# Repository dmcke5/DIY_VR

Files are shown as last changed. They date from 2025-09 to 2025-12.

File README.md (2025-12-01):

# CNCDan - DIY VR
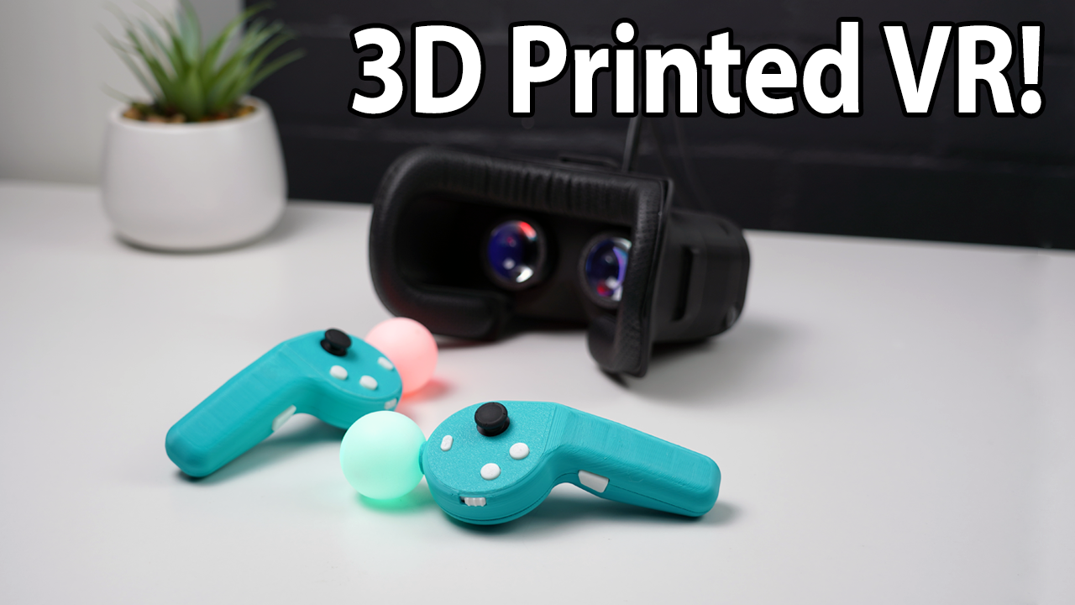
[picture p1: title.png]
DIY VR


A fully 3D printed headset design for VR!

[Project Video Link V1.0](https://youtu.be/pbNyW5GsUQc)

[Project Video Link V2.0](https://youtu.be/7cRuXjuuTN8)

#### Features

- 2880x1440p Resolution
- 120hz Refresh Rate
- Inidividually adjustable IPD
- Easily replaceable lenses
- Compatible with HTC Vive Pro Head Pads
- Adjustable brightness
- SteamVR compatible 3 DOF head tracking or 6DOF using PSMoveServiceEX
- Support for wireless controllers https://github.com/dmcke5/DIY_VR_Controllers

This git has been updated for my Version 2 DIY VR design. All of the original files are still here, they've just been renamed to V1.0 if they are no longer in use (along with the original Readme).

I have included a full model of both versions in .STEP format to aid with assembly!

#### Bill of Materials

1x Display Set - https://www.aliexpress.com/item/32975284107.html

1x GY91 IMU board - https://www.aliexpress.com/item/1005005180963415.html

2x NRF24L01 Wireless Module - https://www.aliexpress.com/item/1005007199963170.html

1x 40mm Ping Pong Balls - https://www.aliexpress.com/item/1005009969506572.html

1x Tactile switch - https://www.aliexpress.com/item/1005006497849129.html

2x 3mm x 145mm Stainless Rod - https://www.aliexpress.com/item/1005009347568195.html

6x 3x6(OD) 4mm(L) Brass Bushings - https://www.aliexpress.com/item/1005008668212038.html

1x Arduino Pro Micro USB-C Version - https://www.aliexpress.com/item/32846843498.html

1x Pair 34mm Diameter 45mm Focal Length Lenses - https://www.aliexpress.com/item/1005004324103470.html

1x 1M 25mm Nylon Strapping - https://www.aliexpress.com/item/1005008515249414.html

1x HTC Vive Pro Face Pad - https://www.aliexpress.com/item/1005001324834346.html

#### Hardware

16x M3x5x5 Threaded Inserts

4x M3x12 SHCS

10x M3x8 SHCS

4x M3x12 Standoffs

### Instructions

#### Printing

First, you'll need one of every part printed, except for these items that require multiples:

3x DIY VR Buckle 

2x DIY VR Lens Retainer

2x DIY VR Thumbscrew Head

The files with V1.0 names can be ignored, unless you are specifically making the old version in which case, you can print them and disregard any V2.0 files. Refer the to V1.0 readme for specific Instructions.

There are print recomendations for most of the important parts in the first video.
The V2.0 front cover is much easier to print than V1.0 and can be printed front down with minimal supports.

#### Electronics

Only three SMD parts are required to assemble the PCB, 1x MCP1792-3302xCB and two 470nF 0603 Capacitors. The two NRF modules can be soldered in as usual, but when you solder in the IMU module ensure you remove the black plastic spacer from the pins to ensure the module is sitting flat against the PCB. The Arduino needs to be installed WITH the black plastic spacers, otherwise its USB port won't align with the opening.

Once the head tracker board is assembled, there are three sets of pads you will need to connect. The two pads labelled "Calibrate" are to be wired to the tactile switch on the side of the headset. The three pads labelled VCC, GND and DO are to be connected to an addressable RGB LED that is used for the pingpong ball.
The final two pads labelled VCC and GND are to supply power to your display driver and should be connected accordingly.

#### Head Tracking Software/Firmware

Revision 2.0 of the head tracker relies on the HadesVR driver. I have included a slightly modified version of their firmware here, which you will need to use as it adds support for the addressable RGB led used for the tracking bulb.

Refer to the HadesVR github page for upload and config instructions: 
https://github.com/HadesVR/Basic-HMD-PCB?tab=readme-ov-file#uploading-the-firmware-and-calibrating-the-sensors

If you're using the 6DOF tracking, you will also need to go through the PSMoveServiceEX Setup process. Their documentation is here: https://github.com/Timocop/PSMoveServiceEx/wiki

#### Physical Build

Refer to both of the project videos for build steps and I will add anything here in future if anyone requests extra information!

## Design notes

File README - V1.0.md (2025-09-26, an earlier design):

# CNCDan - DIY VR
DIY VR

A fully 3D printed headset design for VR!

[Project Video Link](https://youtu.be/pbNyW5GsUQc)

#### Features

- 2880x1440p Resolution
- Inidividually adjustable IPD
- Easily replaceable lenses
- Compatible with HTC Vive Pro Head Pads
- Adjustable brightness
- Duplicate or extend display modes for VR or regular viewing
- SteamVR compatible 3 DOF head tracking

Please note! As I mentioned in the video, the displays I purchased can't actually do the 90hz they claim in the full 2880x1440 display mode which is needed for SteamVR. I'm going to reach out to the company and see if this is just an issue with my unit or if the other 120hz version they sell can actually provide the refresh rate that they claim. I will write back here if/when I get a response!

#### Bill of Materials

1x Display Set (this is the one I used in the video with the issue of not reaching 90hz when in full resolution mode) - https://www.aliexpress.com/item/1005008906958871.html

1x IMU board (any variety that FastIMU supports is fine) - https://www.aliexpress.com/item/1005007284708262.html

2x 3mm x 145mm Stainless Rod - https://www.aliexpress.com/item/1005009347568195.html

6x 3x6(OD) 4mm(L) Brass Bushings - https://www.aliexpress.com/item/1005008668212038.html

1x Arduino Pro Micro USB-C Version - https://www.aliexpress.com/item/32846843498.html

1x Pair 34mm Diameter 45mm Focal Length Lenses - https://www.aliexpress.com/item/1005004324103470.html

1x 1M 25mm Nylon Strapping - https://www.aliexpress.com/item/1005008515249414.html

1x HTC Vive Pro Face Pad - https://www.aliexpress.com/item/1005001324834346.html

#### Hardware

16x M3x5x5 Threaded Inserts

4x M3x12 SHCS

10x M3x8 SHCS

### Instructions

#### Printing

First, you'll need one of every part printed, except for these items that require multiples:

3x DIY VR Buckle 

2x DIY VR Lens Retainer

2x DIY VR Thumbscrew Head

There are print recomendations for most of the important parts in the video, except for the front cover. It's a difficult print to do well, and would ideally be printed back-side down with support interface material enabled. If you can't do multi-material prints, your next best bet would be to print it front-side down and just expect to do some cleanup on the front beveled edges.

#### Electronics

Only four connections are needed between the Arduino and the IMU; VCC, GND, SCL and SDA. If you decide not to use the PCB, you can just wire them manually as follows:
```
 Arduino |  IMU
----------------
  VCC    |  VCC
  GND    |  GND
  D2     |  SDA
  D3     |  SCL
```

Use the +5v and GND pins on the PCB (or equivalent if you're going without the PCB) to power the HDMI driver board from the head tracker module. Use a multimeter to confirm which of the two pads is the ground before you connect anything! On my unit, the circular pad was ground and the square pad was +5v!

#### Head Tracking Software/Firmware

The head tracking relies on the [Relativity VR](https://www.relativty.com/) driver and the FastIMU Arduino library.

To install/flash the FastIMU firmware onto your head tracker, follow this guide: 

https://github.com/relativty/Relativty?tab=readme-ov-file#142-programming-your-mcu

The one thing they don't mention in the guide is that you may need to change the IMU address and name on lines 13 and 14 to match your module. You can flash and run the Example "IMUIdentifier" to find out what values to include.

When you complete the head tracker calibration both in Arduino Studio and later in SteamVR, ensure your headset is sitting flat on the table. You will need to prop it up with something so that the face plate isn't making the unit sit at an angle otherwise your home position will be off.

Next you will need to install and configure the Steam VR driver. Here is a link to the guide!

https://github.com/relativty/Relativty?tab=readme-ov-file#143-installing-the-steamvr-driver

Ensure you follow the guide closely. During the configuration, you will need to set the VID and PID of your board as it will be different to the one used in their drivers. Use the identify board info option in Arduino Studio to display the VID and PID values. They will be in HEX format and need to be converted to Decimal before you can enter them into the configuration!

The window X and Y setting will depend on your PC setup so read the guide for how to set that up, but the correct settings for everything else are as follows:

```
"windowWidth" : 2880,
"windowHeight" : 1440,
"renderWidth" : 2880,
"renderHeight" : 1440,
```

If you can't get through the room setup in SteamVR, chances are you've got something wrong in either the driver configuration or you haven't got the correct IMU selected in the Arduino sketch.

#### Physical Build

Refer to the project video for build steps and I will add anything here in future if anyone requests extra information!

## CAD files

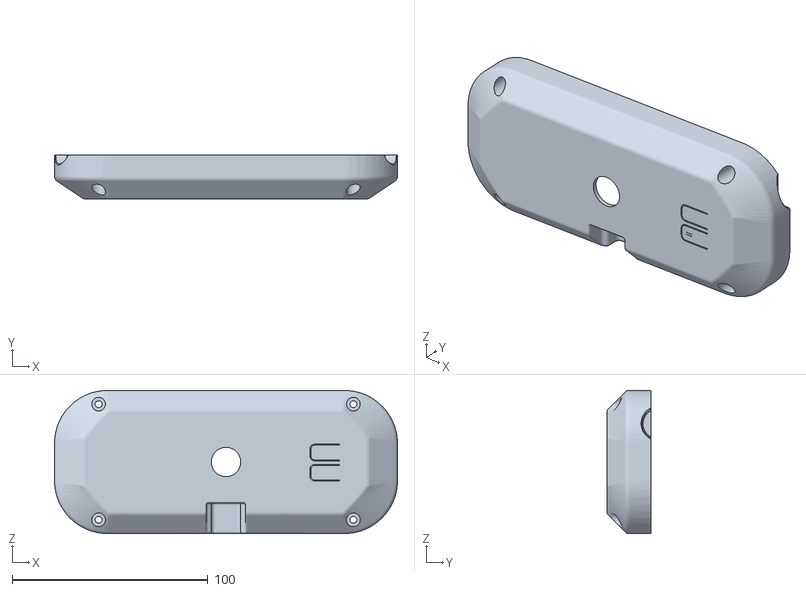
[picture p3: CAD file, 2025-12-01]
STL/DIY VR Housing Front Cover V2.0.STL
175.0 x 22.5 x 73.0

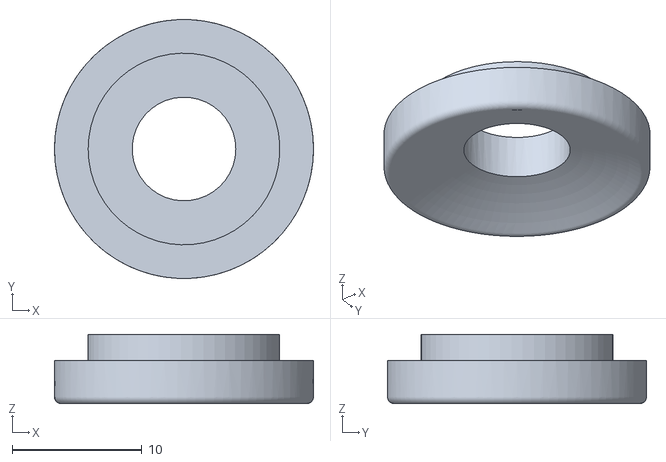
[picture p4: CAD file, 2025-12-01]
STL/DIY VR Headset Ball Mount V2.0.STL
20.0 x 20.0 x 5.33

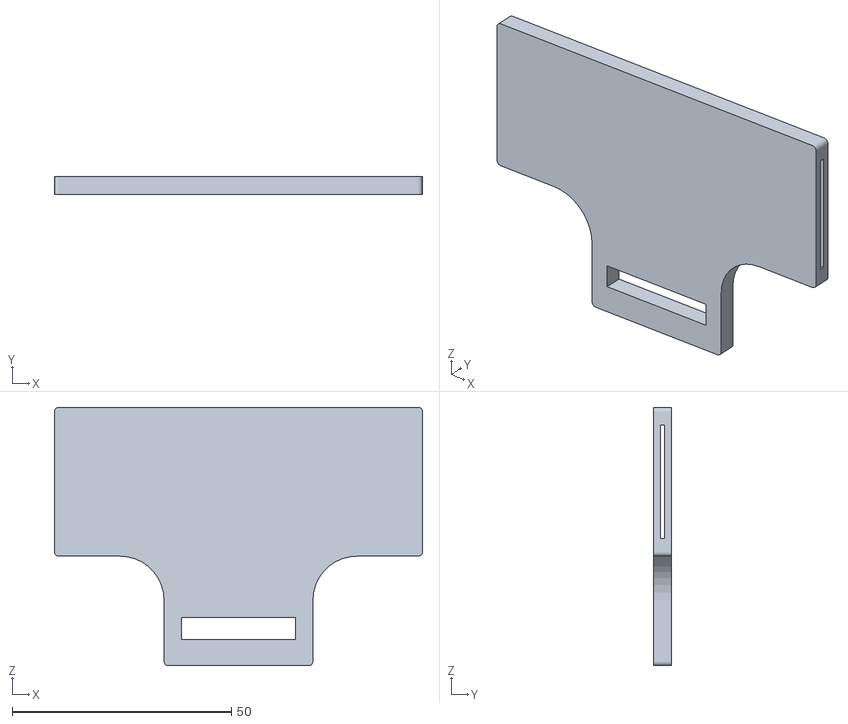
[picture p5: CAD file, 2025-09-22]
STL/DIY VR Head Strap Rear.STL
84.0 x 4.00 x 59.0

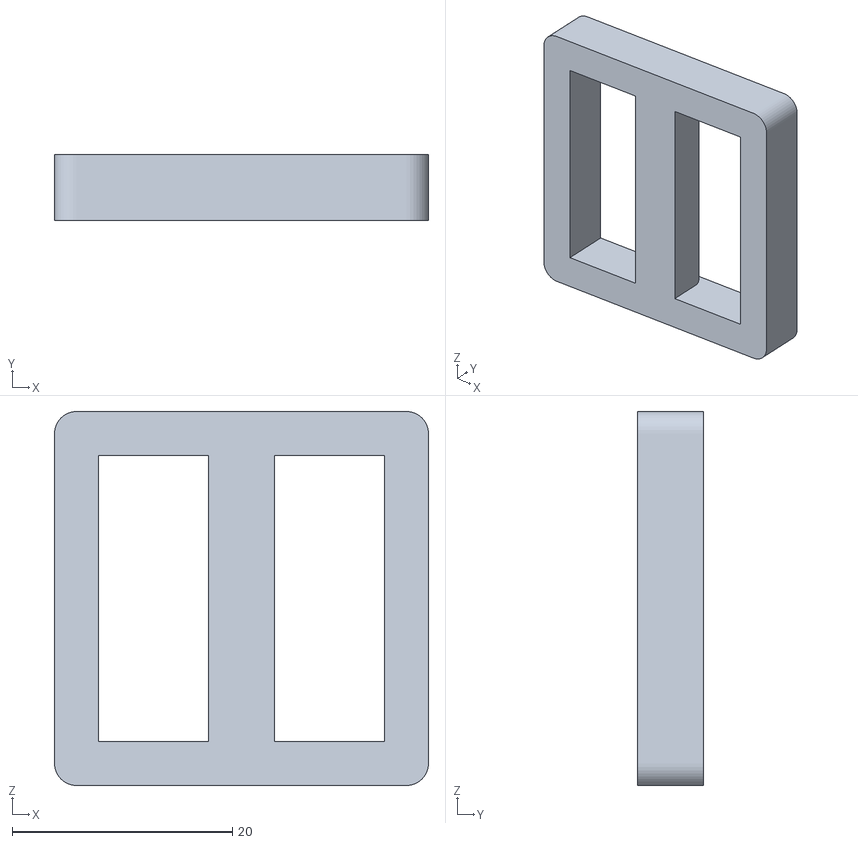
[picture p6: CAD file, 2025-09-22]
STL/DIY VR Buckle.STL
34.0 x 6.00 x 34.0

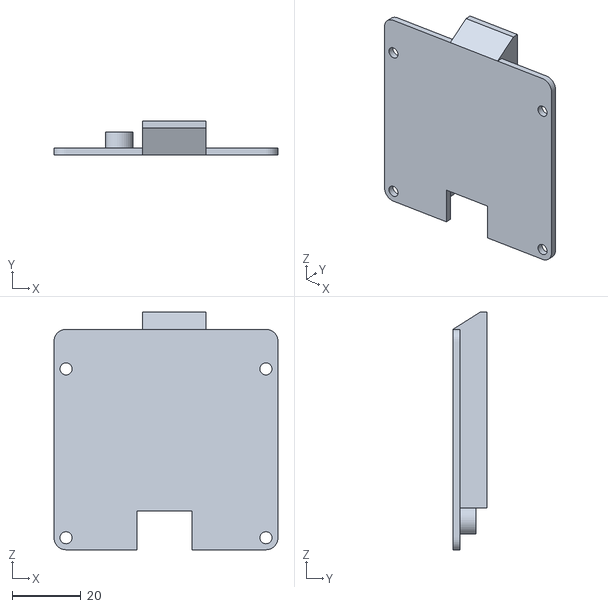
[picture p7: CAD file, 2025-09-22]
STL/DIY VR PCB Mount V1.0.STL
65.0 x 9.82 x 69.0

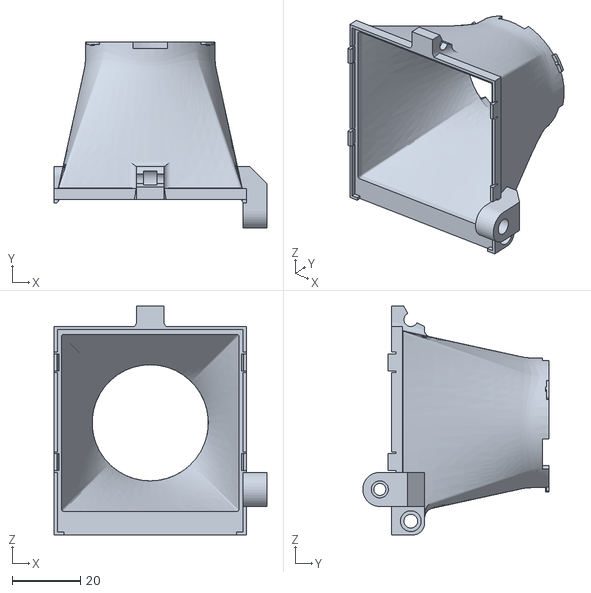
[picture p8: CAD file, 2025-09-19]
STL/DIY VR Eye Box Left.STL
62.2 x 54.6 x 67.0

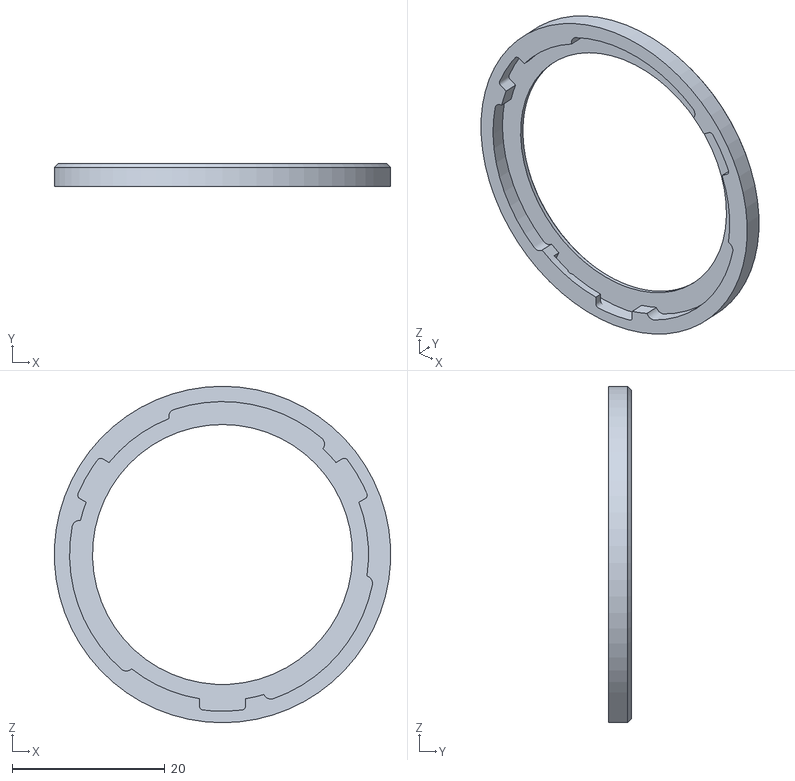
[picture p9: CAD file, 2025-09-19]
STL/DIY VR Lens Retainer.STL
43.9 x 3.00 x 44.0

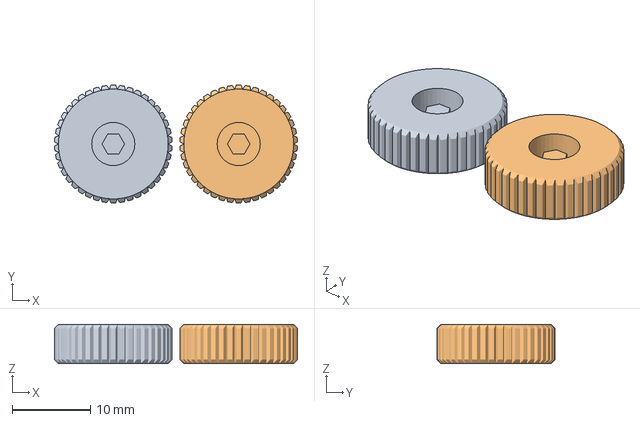
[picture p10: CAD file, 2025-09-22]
STL/DIY VR Thumbscrew Head Multi-Colour.3mf
31.0 x 15.0 x 5.00 mm
M3 SHCS Thumb Screw Head.STL x 2

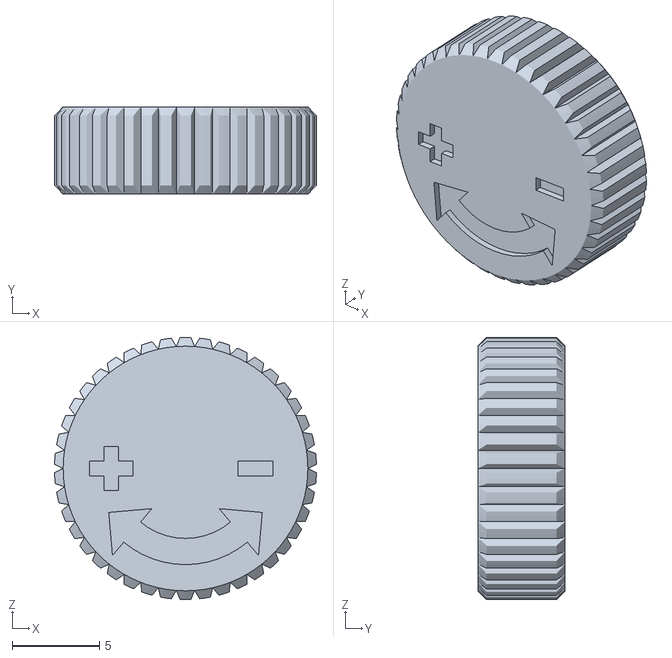
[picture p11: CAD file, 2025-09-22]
STL/DIY VR Thumbscrew Head.STL
15.0 x 5.00 x 15.0

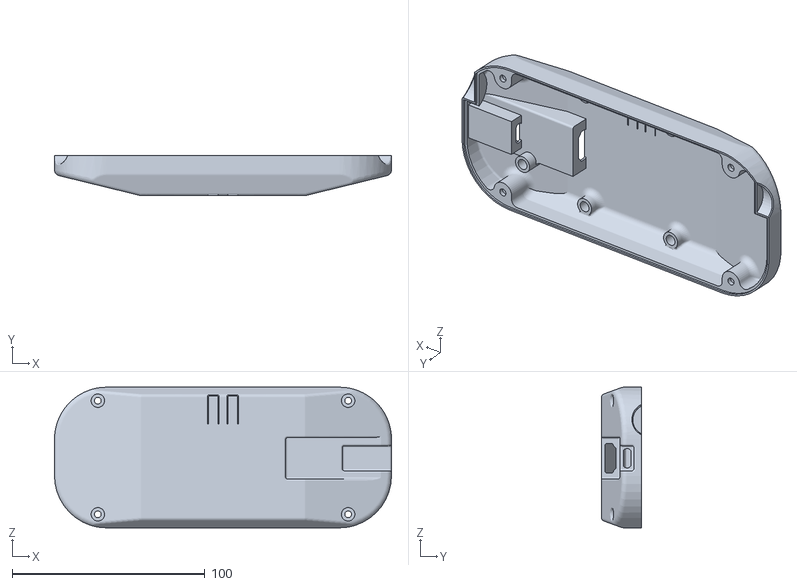
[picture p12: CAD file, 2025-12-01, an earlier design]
STL/DIY VR Housing Front Cover V1.0.STL
175.0 x 21.0 x 73.0

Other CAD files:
STL/DIY VR Eye Box Right.STL

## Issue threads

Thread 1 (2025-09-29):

More a question than an issue

stadros83, 2025-09-29:
Hi, thank you for sharing this amazing DIY VR project!
I was wondering if it’s technically possible to add adjustable lens controls (like a variable focus) so that people with myopia or other vision issues can use it without glasses.
Alternatively, do you think such correction could be handled in software, by simulating the needed optical adjustment?

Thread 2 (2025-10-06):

CAD model format

Mackelaus, 2025-10-06:
Is it possible to get the CAD models solid in .STEP or .STP so that I can modify them? I want to make a themed version of the outer case as well as have the ability to add cameras for possible AR

Closed 2025-10-07.

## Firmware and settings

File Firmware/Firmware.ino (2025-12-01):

/*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
  The above copyright notice and this permission notice shall be included in all copies or substantial portions of the Software.

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
  Modified 2025 - CNCDan
  Added support for RGB Led using FastIMU Library
*/

#include <Wire.h>
#include <EEPROM.h>
#include <SPI.h>
#include "RF24.h"
#include "HID.h"
#include "FastIMU.h"
#include "FastLED.h"

//==========================================================================================================
//************************************ USER CONFIGURABLE STUFF HERE ****************************************
//==========================================================================================================

#define IMU_ADDRESS     0x68                // You can find it out by using the IMUIdentifier example
MPU6500 IMU;                                // IMU type
#define COMMON_CATHODE                      // Uncomment this if your LED is common cathode
#define USE_RF                              // Comment this to disable RF functionality.
#define IMU_GEOMTERY 4                      // Change to your current IMU geomtery (check FastIMU docs for a reference pic).
#define CALIBRATE_FLAT                      // If left uncommented accelerometer/gyro calibration must be done with the flat side of the board pointing down.
//#define SERIAL_DEBUG                        // Uncomment this to make the serial port spicy.

#define NUM_LEDS 1
#define DATA_PIN 7
CRGB leds[NUM_LEDS];

//==========================================================================================================
//************************************ DATA TRANSPORT LAYER ************************************************
//==========================================================================================================

static const uint8_t USB_HID_Descriptor[] PROGMEM = {

  0x06, 0x03, 0x00,   // USAGE_PAGE (vendor defined)
  0x09, 0x00,         // USAGE (Undefined)
  0xa1, 0x01,         // COLLECTION (Application)
  0x15, 0x00,         //   LOGICAL_MINIMUM (0)
  0x26, 0xff, 0x00,   //   LOGICAL_MAXIMUM (255)
  0x85, 0x01,         //   REPORT_ID (1)
  0x75, 0x08,         //   REPORT_SIZE (16)
  0x95, 0x3f,         //   REPORT_COUNT (1)
  0x09, 0x00,         //   USAGE (Undefined)
  0x81, 0x02,         //   INPUT (Data,Var,Abs) - to the host
  0xc0
};

//==========================================================================================================
//************************************* Data packet stuff *************************************************
//==========================================================================================================
struct HMDRAWPacket
{
  uint8_t  PacketID;

  int16_t AccX;
  int16_t AccY;
  int16_t AccZ;

  int16_t GyroX;
  int16_t GyroY;
  int16_t GyroZ;

  int16_t MagX;
  int16_t MagY;
  int16_t MagZ;

  uint16_t HMDData;

  int16_t tracker1_QuatW;
  int16_t tracker1_QuatX;
  int16_t tracker1_QuatY;
  int16_t tracker1_QuatZ;
  uint8_t tracker1_vBat;
  uint8_t tracker1_data;

  int16_t tracker2_QuatW;
  int16_t tracker2_QuatX;
  int16_t tracker2_QuatY;
  int16_t tracker2_QuatZ;
  uint8_t tracker2_vBat;
  uint8_t tracker2_data;

  int16_t tracker3_QuatW;
  int16_t tracker3_QuatX;
  int16_t tracker3_QuatY;
  int16_t tracker3_QuatZ;
  uint8_t tracker3_vBat;
  uint8_t tracker3_data;

};
struct ControllerPacket
{
  uint8_t PacketID;
  int16_t Ctrl1_QuatW;
  int16_t Ctrl1_QuatX;
  int16_t Ctrl1_QuatY;
  int16_t Ctrl1_QuatZ;
  int16_t Ctrl1_AccelX;
  int16_t Ctrl1_AccelY;
  int16_t Ctrl1_AccelZ;
  uint16_t Ctrl1_Buttons;
  uint8_t Ctrl1_Trigger;
  int8_t Ctrl1_axisX;
  int8_t Ctrl1_axisY;
  int8_t Ctrl1_trackY;
  uint8_t Ctrl1_vBat;
  uint8_t Ctrl1_THUMB;
  uint8_t Ctrl1_INDEX;
  uint8_t Ctrl1_MIDDLE;
  uint8_t Ctrl1_RING;
  uint8_t Ctrl1_PINKY;
  uint8_t Ctrl1_AnalogGrip;
  uint16_t Ctrl1_Data;

  int16_t Ctrl2_QuatW;
  int16_t Ctrl2_QuatX;
  int16_t Ctrl2_QuatY;
  int16_t Ctrl2_QuatZ;
  int16_t Ctrl2_AccelX;
  int16_t Ctrl2_AccelY;
  int16_t Ctrl2_AccelZ;
  uint16_t Ctrl2_Buttons;
  uint8_t Ctrl2_Trigger;
  int8_t Ctrl2_axisX;
  int8_t Ctrl2_axisY;
  int8_t Ctrl2_trackY;
  uint8_t Ctrl2_vBat;
  uint8_t Ctrl2_THUMB;
  uint8_t Ctrl2_INDEX;
  uint8_t Ctrl2_MIDDLE;
  uint8_t Ctrl2_RING;
  uint8_t Ctrl2_PINKY;
  uint8_t Ctrl2_AnalogGrip;
  uint16_t Ctrl2_Data;
};

static HMDRAWPacket HMDRawData;
static ControllerPacket ContData;
//==========================================================================================================
//**************************************** RF Data stuff ***************************************************
//==========================================================================================================
const uint64_t rightCtrlPipe = 0xF0F0F0F0E1LL;
const uint64_t leftCtrlPipe = 0xF0F0F0F0D2LL;

RF24 radio1(8, 10); // CE, CSN on radio 1
RF24 radio2(A1, A2); // CE, CSN on radio 2

bool newCtrlData = false;
//==========================================================================================================
//**************************************** IMU variables ***************************************************
//==========================================================================================================
AccelData IMUAccel;
GyroData IMUGyro;
MagData IMUMag;
calData calib = {0};
//==========================================================================================================

#define CALPIN  4
#define CE2     A1
#define CSN2    A2
#define CE1     8
#define CSN1    10

int ledColor = 1;
bool calPressed = false;
bool revTwoBoard = true;
bool serialOpened = false;
bool calNotDone = false;
bool addressableLED = true;

void setup() {
  //Setup Serial
  Serial.begin(115200);

  FastLED.addLeds<WS2811, DATA_PIN, GRB>(leds, NUM_LEDS);

  //Setup HID SubDescriptor
  static HIDSubDescriptor node(USB_HID_Descriptor, sizeof(USB_HID_Descriptor));
  HID().AppendDescriptor(&node);

  //Setup IO
  pinMode(7, OUTPUT);
  pinMode(5, OUTPUT);
  pinMode(6, OUTPUT);
  pinMode(9, OUTPUT);
  pinMode(A0, INPUT);
  pinMode(CALPIN, INPUT_PULLUP);

  //turn on LED
  setColor(7);

#ifdef SERIAL_DEBUG
  while (!Serial) ;
  debugPrintln("[INFO]\tSerial debug active");
#endif

  //Check board revision
  pinMode(A3, INPUT_PULLUP);
  if (digitalRead(A3)) {
    debugPrintln("[INFO]\tBoard revision: 1.X");
    //revTwoBoard = false;
  }
  else {
    debugPrintln("[INFO]\tBoard revision: 2.X");
    //revTwoBoard = true;
  }

  //Set up RF radios
#ifdef USE_RF
  //start up radio 1
  radio1.begin();
  radio1.setPayloadSize(32);
  radio1.setAutoAck(false);
  radio1.setDataRate(RF24_2MBPS);
  radio1.setPALevel(RF24_PA_LOW);
  radio1.startListening();
  //start up radio 2
  if (revTwoBoard) {
    radio2.begin();
    radio2.setPayloadSize(32);
    radio2.setAutoAck(false);
    radio2.setDataRate(RF24_2MBPS);
    radio2.setPALevel(RF24_PA_LOW);
    radio2.startListening();
  }
  if (!radio1.isChipConnected())
  {
    debugPrintln("[ERROR]\tRadio 1 Not Found!");
    errorBlink(1);    //Radio 1 is the main radio, shouldn't run without it.
  }
  else {
    debugPrintln("[INFO]\tRadio 1 Initialized");
    radio1.openReadingPipe(1, rightCtrlPipe);
    if (!revTwoBoard) {
      radio1.openReadingPipe(2, leftCtrlPipe);
    }
  }
  if (revTwoBoard) {
    if (!radio2.isChipConnected())
    {
      debugPrintln("[ERROR]\tRadio 2 Not Found!");
      debugPrintln("[INFO]\tFalling back to single radio mode");
      radio1.openReadingPipe(2, leftCtrlPipe);
    }
    else
    {
      debugPrintln("[INFO]\tRadio 2 Initialized");
      radio2.openReadingPipe(1, leftCtrlPipe);
    }
  }
#endif

  //Start up I2C
  Wire.begin();
  Wire.setClock(400000); //400khz clock

  //Initialize IMU
  IMU.setIMUGeometry(IMU_GEOMTERY);
  int err = IMU.init(calib, IMU_ADDRESS);
  if (err != 0)
  {
    debugPrint("[ERROR]\tIMU ERROR: ");
    debugPrintln(err);
    errorBlink(0);
  }
  debugPrintln("[INFO]\tIMU Initialized.");

  EEPROM.get(100, ledColor);
  if (ledColor > 6) {
    ledColor = 0;
  }
  setColor(ledColor);

  HMDRawData.PacketID = 3;
  ContData.PacketID = 2;

  int t;
  EEPROM.get(125, t);
  if (!(t == 99)) {
    debugPrintln("[INFO]\tCalibration not valid!");
    calNotDone = true;
    while (!Serial) {
      setColor(6);
      delay(500);
      setColor(7);
      delay(500);
    }
  }
  else {
    //calibration is valid
    EEPROM.get(200, calib);
    IMU.init(calib, IMU_ADDRESS);     //Reinitialize with correct calibration values
    debugPrintln("[INFO]\tLoaded Calibration from EEPROM!");
#ifdef SERIAL_DEBUG
    printCalibration();
#endif
  }
}

void loop()
{
  //run Serial
  if (Serial) {
    if (!serialOpened) {
      if (calNotDone) {
        Serial.println("[INFO]\tNo calibration data detected, do you want to enter calibration mode? (y/n)");
      } else {
        Serial.println("[INFO]\tSerial monitor open, do you want to enter calibration mode? (y/n)");
      }
    }
    serialOpened = true;
    if (Serial.read() == 'y') {
      setColor(7);
      calib = { 0 };                    //this looks important
#ifdef CALIBRATE_FLAT
      IMU.setIMUGeometry(0);
#endif
      IMU.init(calib, IMU_ADDRESS);
      Serial.println("[INFO]\tCalibrating IMU... Keep headset still on a flat and level surface...");
      delay(10000);
      IMU.calibrateAccelGyro(&calib);
      IMU.init(calib, IMU_ADDRESS);
      Serial.println("[INFO]\tAccelerometer and Gyroscope calibrated!");
      if (IMU.hasMagnetometer()) {
        delay(1000);
        Serial.println("[INFO]\tMagnetometer calibration: move IMU in figure 8 pattern until done.");
        delay(5000);
        IMU.calibrateMag(&calib);
        Serial.println("[INFO]\tMagnetic calibration done!");
      }
      Serial.println("[INFO]\tIMU Calibration complete!");
      Serial.println("[INFO]\tAccel biases X/Y/Z: ");
      Serial.print("[INFO]\t");
      Serial.print(calib.accelBias[0]);
      Serial.print(", ");
      Serial.print(calib.accelBias[1]);
      Serial.print(", ");
      Serial.println(calib.accelBias[2]);
      Serial.println("[INFO]\tGyro biases X/Y/Z: ");
      Serial.print("[INFO]\t");
      Serial.print(calib.gyroBias[0]);
      Serial.print(", ");
      Serial.print(calib.gyroBias[1]);
      Serial.print(", ");
      Serial.println(calib.gyroBias[2]);
      if (IMU.hasMagnetometer()) {
        Serial.println("[INFO]\tMag biases X/Y/Z: ");
        Serial.print("[INFO]\t");
        Serial.print(calib.magBias[0]);
        Serial.print(", ");
        Serial.print(calib.magBias[1]);
        Serial.print(", ");
        Serial.println(calib.magBias[2]);
        Serial.println("[INFO]\tMag Scale X/Y/Z: ");
        Serial.print("[INFO]\t");
        Serial.print(calib.magScale[0]);
        Serial.print(", ");
        Serial.print(calib.magScale[1]);
        Serial.print(", ");
        Serial.println(calib.magScale[2]);
      }
      setColor(4);
      Serial.println("[INFO]\tSaving Calibration values to EEPROM!");
      EEPROM.put(200, calib);
      EEPROM.put(125, 99);
      delay(1000);
      Serial.println("[INFO]\tYou can now close the Serial monitor.");
      delay(5000);
      IMU.setIMUGeometry(IMU_GEOMTERY);
      IMU.init(calib, IMU_ADDRESS);
      setColor(ledColor);
    }
  }

  //run IMU
  IMU.update();
  IMU.getAccel(&IMUAccel);
  IMU.getGyro(&IMUGyro);

  if (IMU.hasMagnetometer()) {
    IMU.getMag(&IMUMag);
    HMDRawData.MagX = (short)(IMUMag.magX * 5);
    HMDRawData.MagY = (short)(IMUMag.magY * 5);
    HMDRawData.MagZ = (short)(IMUMag.magZ * 5);
  }
  else {
    HMDRawData.MagX = (short)(0);
    HMDRawData.MagY = (short)(0);
    HMDRawData.MagZ = (short)(0);
  }

  HMDRawData.AccX = (short)(IMUAccel.accelX * 2048);
  HMDRawData.AccY = (short)(IMUAccel.accelY * 2048);
  HMDRawData.AccZ = (short)(IMUAccel.accelZ * 2048);

  HMDRawData.GyroX = (short)(IMUGyro.gyroX * 16);
  HMDRawData.GyroY = (short)(IMUGyro.gyroY * 16);
  HMDRawData.GyroZ = (short)(IMUGyro.gyroZ * 16);

  //run RF
  uint8_t pipenum;
  if (radio1.available(&pipenum)) {                  //thanks SimLeek for this idea!
    if (pipenum == 1) {
      radio1.read(&ContData.Ctrl1_QuatW, 29);        //receive right controller data
      debugPrintln("RX 1, Right Controller!");
      newCtrlData = true;
    }
    if (pipenum == 2) {
      radio1.read(&ContData.Ctrl2_QuatW, 29);        //receive left controller data
      debugPrintln("RX 1, Left Controller!");
      newCtrlData = true;
    }
  }
  if (radio2.available(&pipenum) && revTwoBoard) {
    radio2.read(&ContData.Ctrl2_QuatW, 29);        //receive left controller data
    debugPrintln("RX 2, Left controller!");
    newCtrlData = true;
  }
  if (newCtrlData) {
    HID().SendReport(1, &ContData, 63);
    newCtrlData = false;
  }

  //run LED
  if (!digitalRead(CALPIN)) {
    if (!calPressed) {
      calPressed = true;
      ledColor++;
      if (ledColor > 6) {
        ledColor = 0;
      }
      debugPrintln("[INFO]\tswitched LED color and saved new value");
      setColor(ledColor);
      EEPROM.put(100, ledColor);
      delay(40);
    }
  }
  else {
    calPressed = false;
  }
  HID().SendReport(1, &HMDRawData, 63);
}

void printCalibration()
{
  Serial.println("[INFO]\tAccel biases X/Y/Z: ");
  Serial.print("[INFO]\t");
  Serial.print(calib.accelBias[0]);
  Serial.print(", ");
  Serial.print(calib.accelBias[1]);
  Serial.print(", ");
  Serial.println(calib.accelBias[2]);
  Serial.println("[INFO]\tGyro biases X/Y/Z: ");
  Serial.print("[INFO]\t");
  Serial.print(calib.gyroBias[0]);
  Serial.print(", ");
  Serial.print(calib.gyroBias[1]);
  Serial.print(", ");
  Serial.println(calib.gyroBias[2]);
  if (IMU.hasMagnetometer()) {
    Serial.println("[INFO]\tMag biases X/Y/Z: ");
    Serial.print("[INFO]\t");
    Serial.print(calib.magBias[0]);
    Serial.print(", ");
    Serial.print(calib.magBias[1]);
    Serial.print(", ");
    Serial.println(calib.magBias[2]);
    Serial.println("[INFO]\tMag Scale X/Y/Z: ");
    Serial.print("[INFO]\t");
    Serial.print(calib.magScale[0]);
    Serial.print(", ");
    Serial.print(calib.magScale[1]);
    Serial.print(", ");
    Serial.println(calib.magScale[2]);
  }
}
void ledControl(int red, int green, int blue)
{
  if(!addressableLED){
    #ifdef COMMON_CATHODE
      digitalWrite(7, LOW);
      digitalWrite(5, red);
      digitalWrite(6, green);
      digitalWrite(9, blue);
    #else
      digitalWrite(7, HIGH);
      digitalWrite(5, !red);
      digitalWrite(6, !green);
      digitalWrite(9, !blue);
    #endif
  } else {
    leds[0] = CRGB((red * 255), (green * 255), (blue * 255));
    FastLED.show();
  }
}

void setColor(int index) {
  switch (index) {
    case 0:
      ledControl(1, 0, 0);    //red
      break;
    case 1:
      ledControl(1, 1, 0);    //yellow
      break;
    case 2:
      ledControl(0, 1, 0);    //green
      break;
    case 3:
      ledControl(0, 1, 1);    //cyan
      break;
    case 4:
      ledControl(0, 0, 1);    //blue
      break;
    case 5:
      ledControl(1, 0, 1);    //magenta
      break;
    case 6:
      ledControl(0, 0, 0);    //off
      break;
    case 7:
      ledControl(1, 1, 1);    //white
      break;
    default:
      ledControl(1, 0, 0);    //red again
      break;
  }
}

void debugPrint(String arg) {
#ifdef SERIAL_DEBUG
  Serial.print(arg);
#endif
}
void debugPrint(int arg) {
#ifdef SERIAL_DEBUG
  Serial.print(arg);
#endif
}
void debugPrintln(String arg) {
#ifdef SERIAL_DEBUG
  Serial.println(arg);
#endif
}
void debugPrintln(int arg) {
#ifdef SERIAL_DEBUG
  Serial.println(arg);
#endif
}

void errorBlink(int color)
{
  while (true)
  {
    setColor(color);
    delay(500);
    setColor(6);
    delay(500);
  }
}

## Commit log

2025-09-19 Added files for PCB
    [DIY VR.kicad_pcb, DIY VR.kicad_sch]
2025-09-19 Added STL's
    [DIY VR Eye Box Left.STL, DIY VR Eye Box Right.STL, DIY VR Lens Retainer.STL]
2025-09-22 Added full assembly model and STL's
    [DIY VR Buckle.STL, DIY VR Head Strap Rear.STL, DIY VR PCB Mount.STL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]
2025-12-01 Updated to V2.0!
    [DIY VR Headset Ball Mount V2.0.STL, DIY VR Housing Front Cover V1.0.STL, DIY VR Housing Front Cover V2.0.STL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]

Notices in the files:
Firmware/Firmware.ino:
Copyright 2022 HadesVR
